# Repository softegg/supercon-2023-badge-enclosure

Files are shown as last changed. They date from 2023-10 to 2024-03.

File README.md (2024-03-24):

# supercon-2023-badge-enclosure
This is an enclosure for the Hackaday Supercon 2023 / Hackaday Berlin 2024 Vectorscope badge, which appears on GitHub here:
https://github.com/Hack-a-Day/Vectorscope/tree/main

These files are available for anybody to 3d print, modify, remix, etc. in advance of the 2023 Hackaday Superconference and Hackaday Berlin 2024 event, so that they might have an elegant enclosure for their badge.

I make them available under the Creative Commons Attribution-NonCommercial-ShareAlike 4.0 International License, which basically means you can do anything you want with this except make money on it. Only I can do that. Having posted it to GitHub implies that they might be getting some advantage out of it, and sharing pictures of it is fine, but please reproduce the license with any of the models you wish to redistribute.

https://creativecommons.org/licenses/by-nc-sa/4.0/deed.en

The intention is that there will be multiple versions of this enclosure.

Basic-2 is the most basic version (The original BASIC is depreciated; it was an early revision that didn't fit together well and you shouldn't use it anymore.) It is designed as a jumping off point for more elaborate designs with a simple, clean, rounded shape that shouldn't hurt you if you are wearing it.

BASIC-2-HACKING is a double sized version that is designed to fit the badge hacking expansion board as well. There is plenty of blank space for you to add your own controls, connectors, displays, stickers, whatever, and you are encouraged with both designs to remix them for whatever your hacking/aesthetic needs are!

If you print one and come to the show, I'd really like to get a selfie with you and your version of the badge, or if you are sensitive about your picture, I could just take a selfie with your badge. It was great fun at Supercon, and I hope to see a lot of these at Berlin 2024 as well!

The BASIC-2 Enclosure
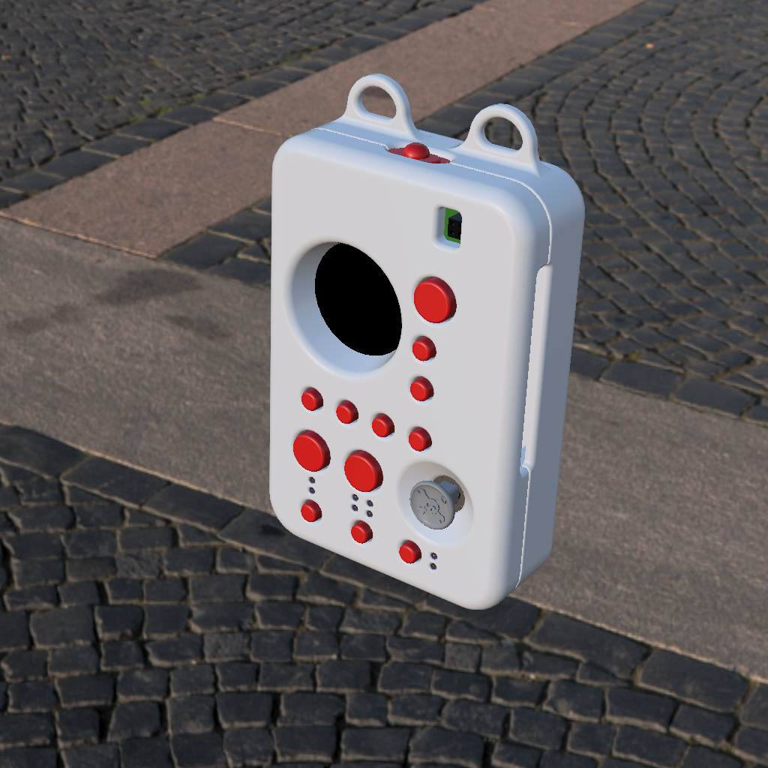
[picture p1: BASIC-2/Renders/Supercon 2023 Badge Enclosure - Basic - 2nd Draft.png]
The BASIC-2 Enclosure as rendered from Fusion 360


The BASIC-2-HACKING Enclosure
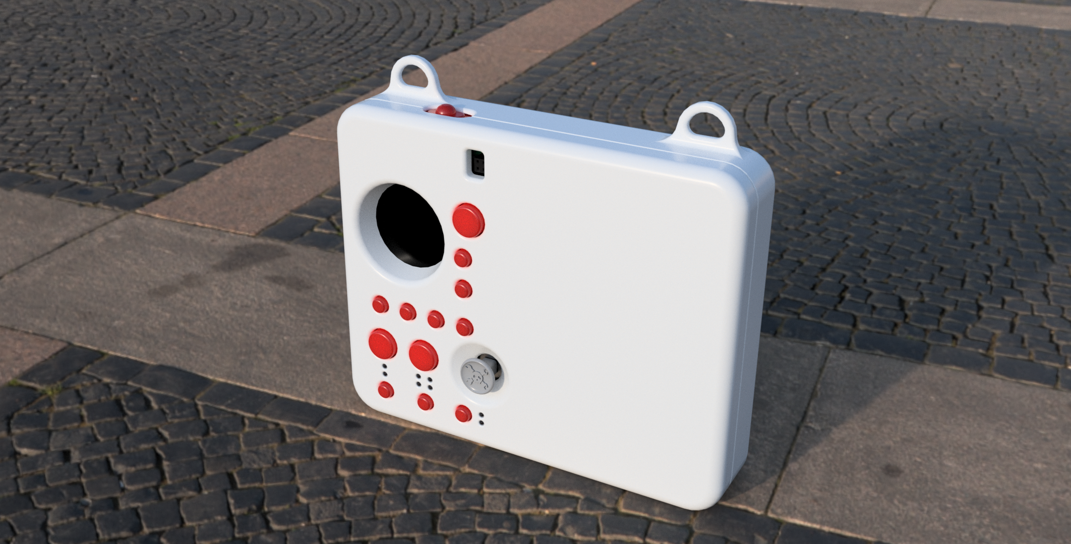
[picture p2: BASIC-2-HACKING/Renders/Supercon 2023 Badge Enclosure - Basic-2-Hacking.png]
The BASIC-2-HACKING Enclosure as rendered from Fusion 360


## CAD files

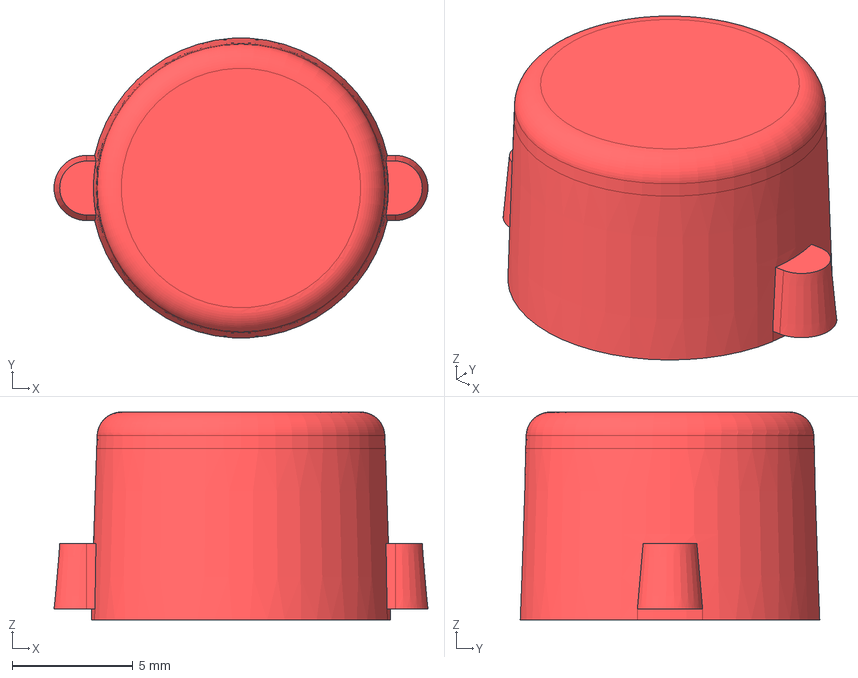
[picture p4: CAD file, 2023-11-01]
BASIC-2-HACKING/STEP/Menu Button - Supercon 2023 Badge Enclosure - Basic-2-Hacking.step
15.5 x 12.4 x 8.60 mm

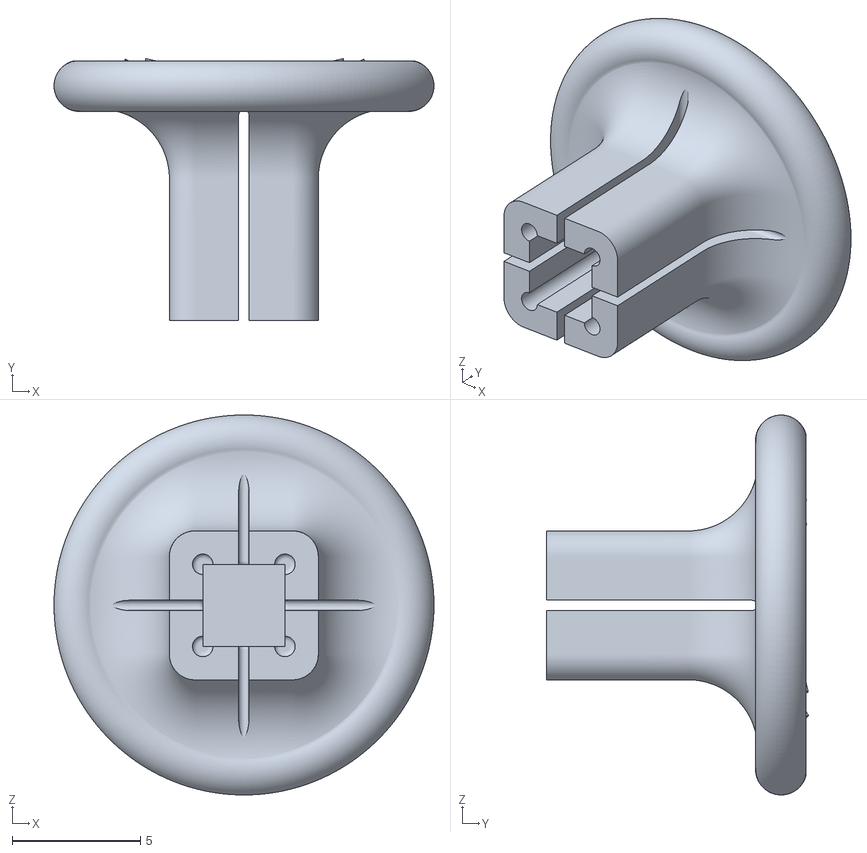
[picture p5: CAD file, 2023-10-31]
BASIC-2-HACKING/STL/Joystick - Supercon 2023 Badge Enclosure - Basic-2-Hacking.stl
14.8 x 10.2 x 14.8

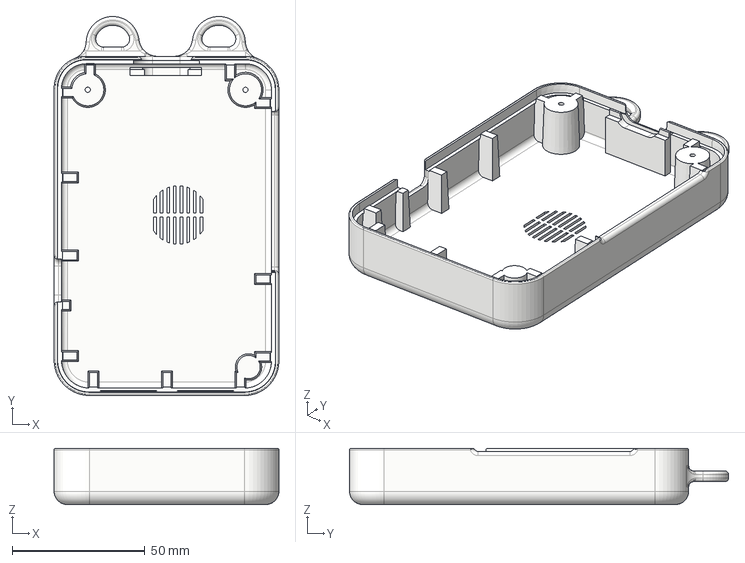
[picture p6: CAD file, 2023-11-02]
BASIC-2/STEP/Back - Supercon 2023 Badge Enclosure - Basic-2.step
84.6 x 142.6 x 21.1 mm

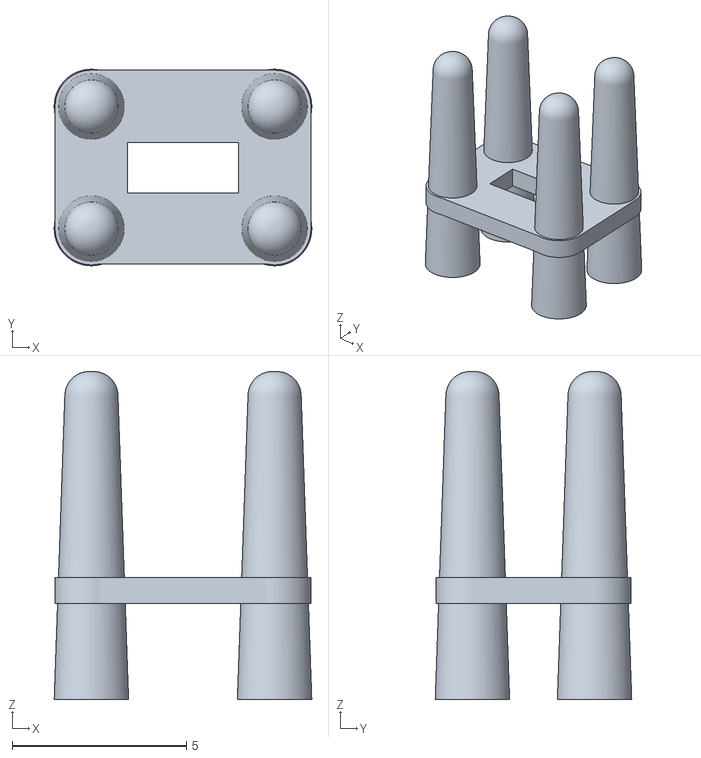
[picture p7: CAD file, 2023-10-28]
BASIC-2/STL/Lightpipe 2z2 - Supercon 2023 Badge Enclosure - BASIC-2.stl
7.38 x 5.63 x 9.40

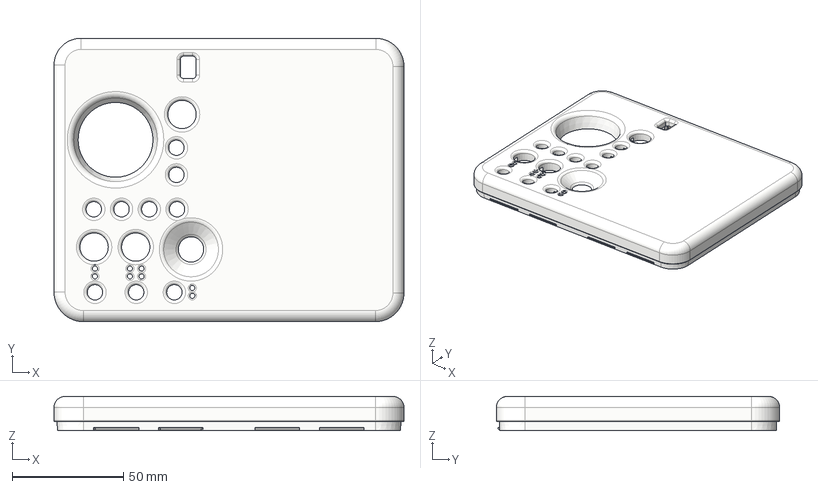
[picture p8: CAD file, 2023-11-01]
BASIC-2-HACKING/STEP/Front - Supercon 2023 Badge Enclosure - Basic-2-Hacking.step
157.6 x 127.6 x 15.4 mm

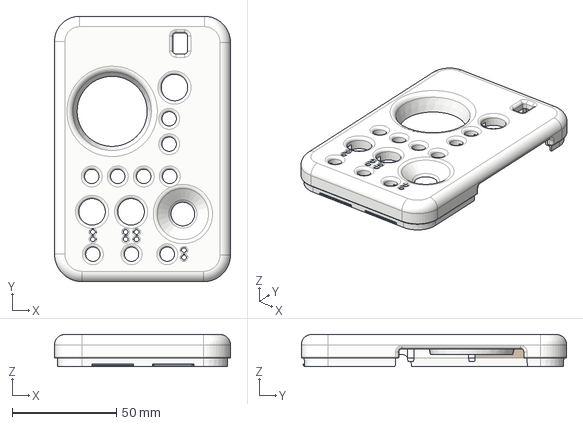
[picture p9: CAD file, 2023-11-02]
BASIC-2/STEP/Front - Supercon 2023 Badge Enclosure - Basic-2.step
84.6 x 127.6 x 15.4 mm

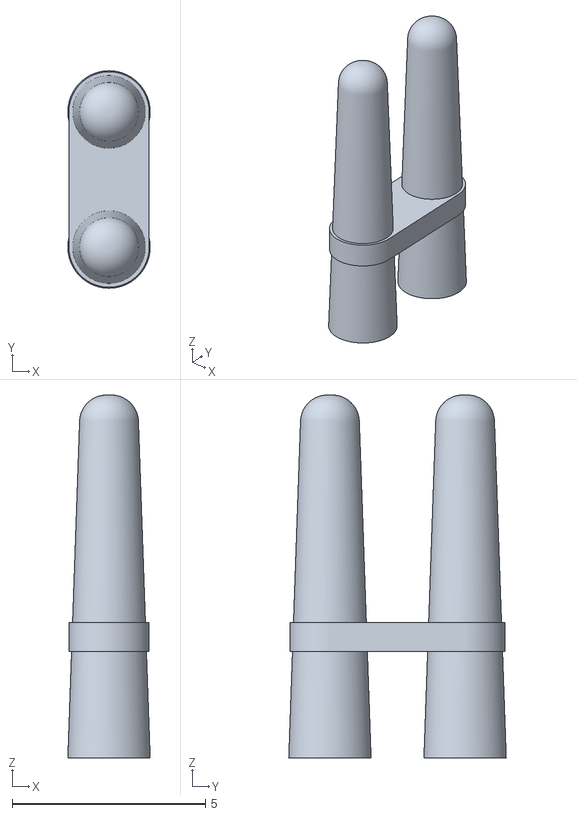
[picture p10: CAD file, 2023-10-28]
BASIC-2/STL/Lightpipe 1x2 - Supercon 2023 Badge Enclosure - BASIC-2.stl
2.13 x 5.63 x 9.40

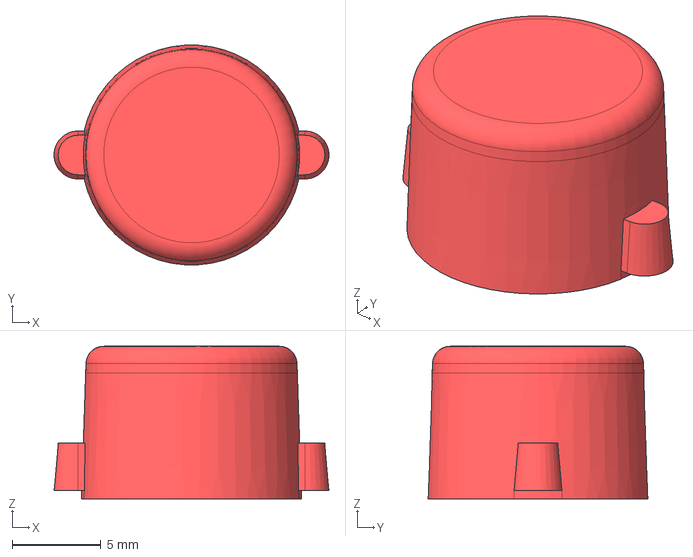
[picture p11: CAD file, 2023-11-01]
BASIC-2-HACKING/STEP/Level Button - Supercon 2023 Badge Enclosure - Basic-2-Hacking.step
15.5 x 12.4 x 8.60 mm

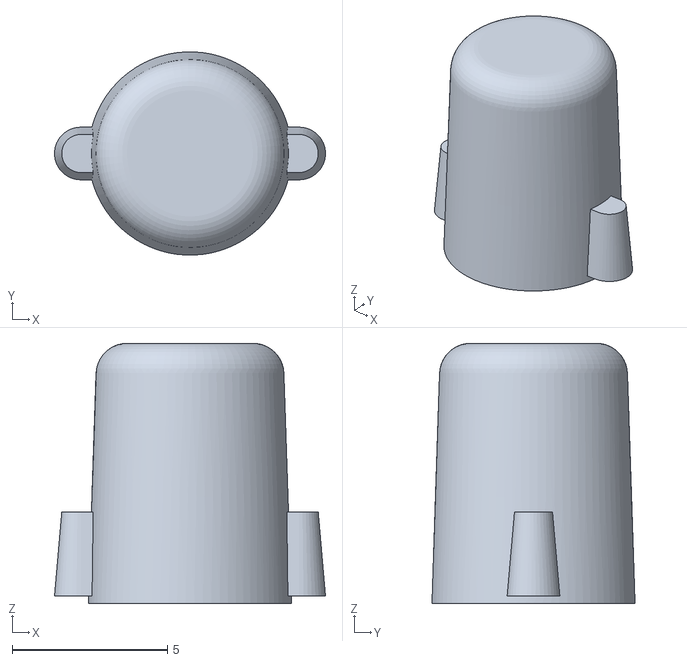
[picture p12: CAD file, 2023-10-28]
BASIC-2/STL/Button C.stl - Supercon 2023 Badge Enclosure - BASIC-2.stl
8.74 x 6.55 x 8.40

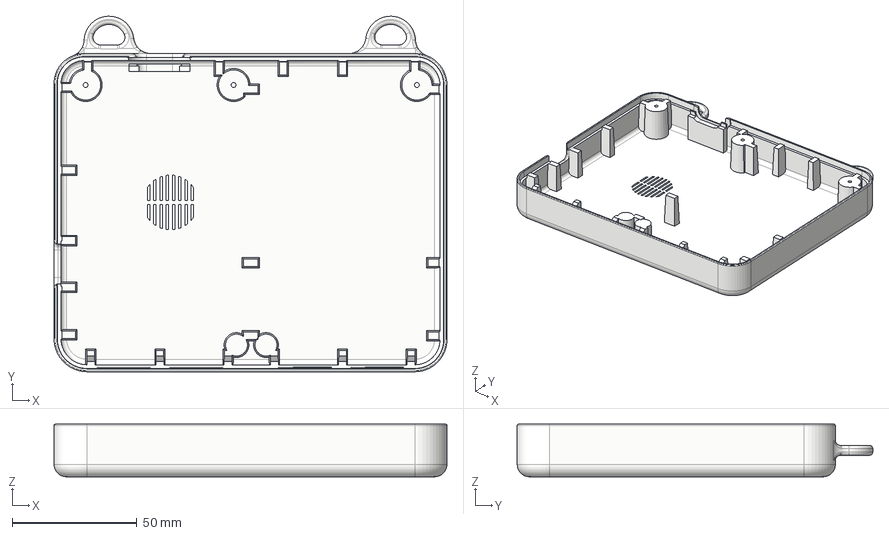
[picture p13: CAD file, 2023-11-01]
BASIC-2-HACKING/STEP/Back - Supercon 2023 Badge Enclosure - Basic-2-Hacking.step
157.6 x 142.6 x 21.1 mm

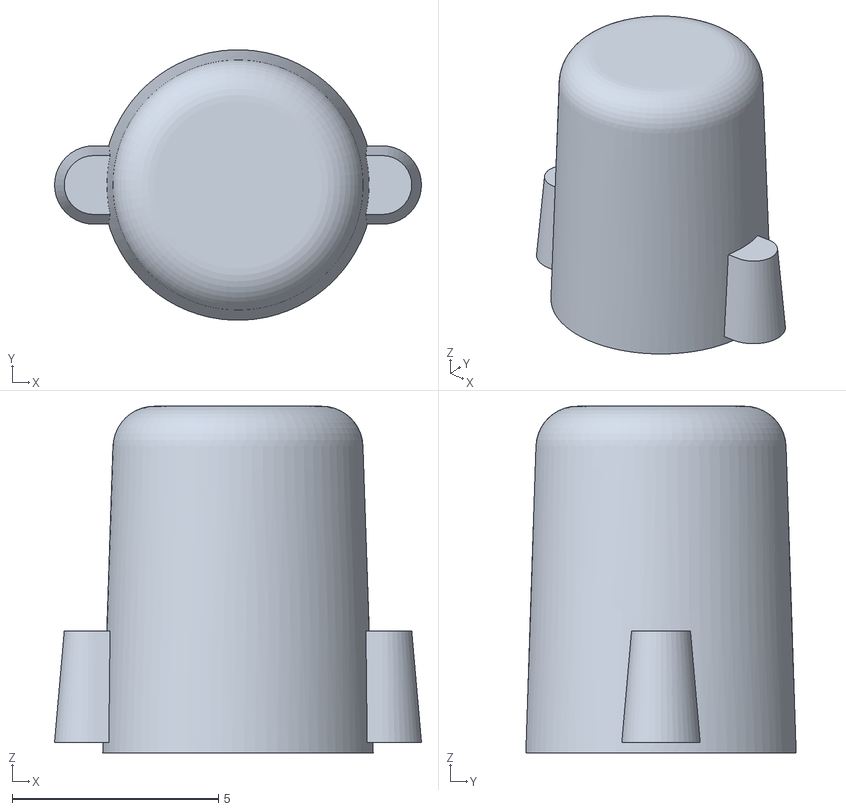
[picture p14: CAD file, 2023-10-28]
BASIC-2/STL/XY - Supercon 2023 Badge Enclosure - BASIC-2.stl
8.90 x 6.55 x 8.40

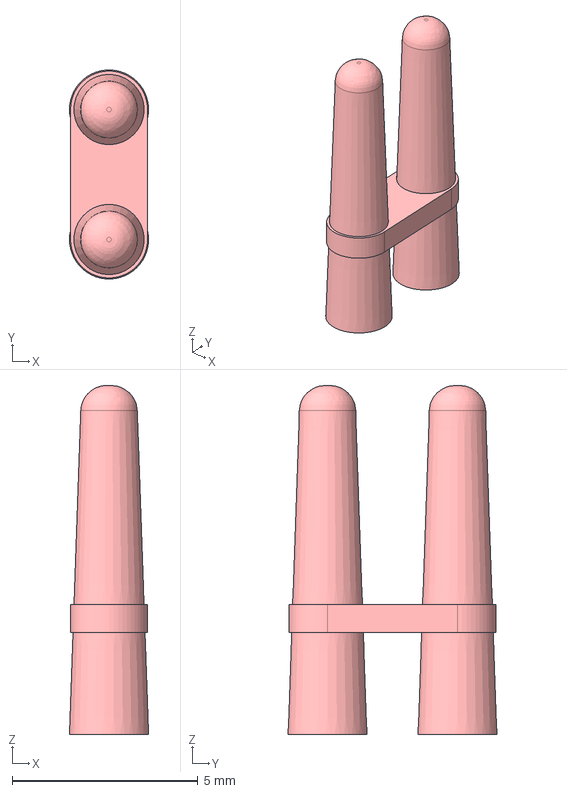
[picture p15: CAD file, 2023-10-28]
BASIC-2/STEP/Lightpipe 1x2 B - Supercon 2023 Badge Enclosure - Basic-2.step
2.13 x 5.63 x 9.40 mm

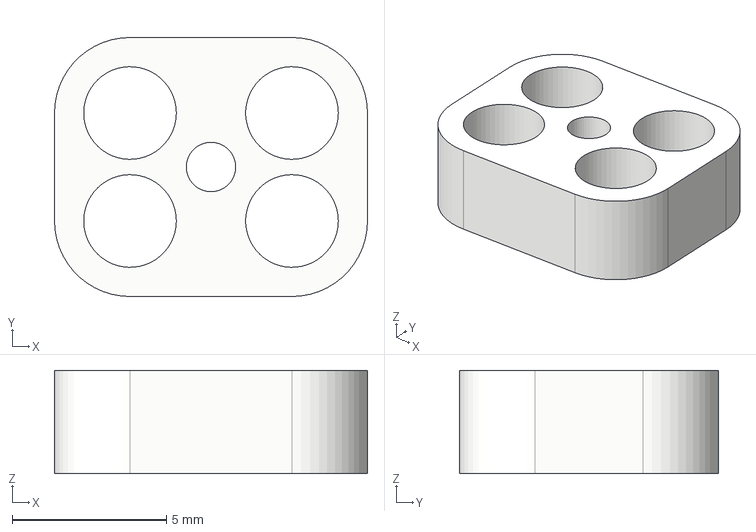
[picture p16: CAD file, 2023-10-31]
BASIC-2-HACKING/STEP/Lightpipe 2x2 Shield - Supercon 2023 Badge Enclosure - Basic-2-Hacking.step
10.1 x 8.39 x 3.35 mm

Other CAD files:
BASIC-2/STEP/Joystick - Supercon 2023 Badge Enclosure - Basic-2.step
BASIC-2/STEP/Lightpipe 2x2 - Supercon 2023 Badge Enclosure - Basic-2.step
BASIC-2-HACKING/STEP/Range Button - Supercon 2023 Badge Enclosure - Basic-2-Hacking.step
BASIC-2/STL/Button B.stl - Supercon 2023 Badge Enclosure - BASIC-2.stl
BASIC-2/STEP/Lightpipe 1x2A - Supercon 2023 Badge Enclosure - Basic-2.step
BASIC-2-HACKING/STEP/Button A - Supercon 2023 Badge Enclosure - Basic-2-Hacking.step
BASIC-2-HACKING/STEP/Button B - Supercon 2023 Badge Enclosure - Basic-2-Hacking.step
BASIC-2-HACKING/STEP/Button C - Supercon 2023 Badge Enclosure - Basic-2-Hacking.step
BASIC-2-HACKING/STEP/Button D - Supercon 2023 Badge Enclosure - Basic-2-Hacking.step
BASIC-2-HACKING/STEP/Lightpipe 1x2 A - Supercon 2023 Badge Enclosure - Basic-2-Hacking.step
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

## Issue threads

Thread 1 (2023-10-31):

Enclosure as a teachable experience

frankcohen, 2023-10-31:
Hi @softegg thanks for the case, I'm going to print it on a Elegoo Saturn resin printer in a clear resin. I'm working on my Reflections open-source wrist watch project https://github.com/frankcohen/ReflectionsOS. I've been wondering how I can make press-able buttons on the watch case that would activate SMT buttons on its main board. I'm hoping your badge enclosure will teach me about buttons.

One thing that concerns me about your enclosure... so many objects to print! Wow.

Thank you.

-Frank

softegg, 2023-10-31:
The best teacher is always to take apart some things that work the way you want your project to work and see what they did.

For buttons, the main things are that they don't bind and they don't fall in the case. If you have labels on them, maybe make sure they don't spin also.
Having a draft angle that makes them smaller near the top helps keep them in the case, but it is good to have some sort of a lip also. I used the spin prevention nubs for that, but that kinda means you can see LEDs blinking in the case around the buttons, so maybe I coulda done better with a full lip.
The design very much depends on what they are actually pushing, whether they can attach to that, if they need to come off for cleaning, how deep you enclosure is, etc.

You prototype until you have something that works, and try to produce it with a process that gets you as close to your finished process as possible.

In injection molding, you need draft angle to you can get the parts out of the mold, and vents so that the air has a way to escape when they plastic comes in. If it's deep, you might need a pusher to push the part out of the mold. And you need an easy parting line where the mold separate and the draft angle reverses. Oh, and an injection point for the plastic to go in.
Any hole or edge leaves a scar or sprue, so you want this in areas that you can't see, and that won't cause a mechanical failure to the motion of the button.
Resin casting is similar, but more forgiving because the silicon molds bend, but then you have to worry about part warping too, on larger parts. Also, mold release is really important so as not to tear the mold.

If you are 3d printing, you have different concerns. Resin is mainly about where your supports go, how resin drains, and build plate adhesion.
FDM has support, infill, grain, bed adhesion, resolution and a while host of other issues.

So you design your posts with your manufacturing process, both prototyping and manufacturing, in mind, as well as the mechanical function, and aesthetics.

It's fun, but there are always revisions and tweaks before you get it right. I'm amazed that the first draft enclosure came out as good as it did, TBH. But even that had buttons that bind...

Anyway, good luck. I'm available for hire if you don't want to do it yourself...

frankcohen, 2023-11-01:
Thanks for the advice, I appreciate you writing your advice to me.

I'm a software guy who is learning by doing a combination hardware/software project. Reflections first instance is a wrist watch. There are two surface mounted switches on the main board. They have push button pins on their sides. I need 2 easy buttons to be at the watch case and reach in to press the buttons on the main board.

My plan is to prototype the watch case using clear resin (printed on an Elegoo Saturn printer), then take the final prototypes to a manufacturer. The manufacturer builds the case design to be milled from stainless steel. I would be fine if you tell me not to do this process?

Not so great progress on printing the Supercon board protector today. Trying again tomorrow.

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

-Frank

Closed 2024-03-24.

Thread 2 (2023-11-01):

Printing All At Once

frankcohen, 2023-11-01:
My first print experiences for the enclosure didn't go so well. :-D
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

I rotated the case to keep it from adhering to the build plate. Instead, that's just what it did. :-o

My attempt today is to print all the components all at once. It's my homage to Jobu Tupaki, "I got bored one day and put everything on a bagel." Although perhaps this strategy will be more like Evelyn saying 'We are all small and stupid."

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

6 1/2 hours, 1,792 layers, and a full tank of water-washable clear resin... what could go wrong?

Please wish me luck!

See you all tomorrow!

-Frank

softegg, 2023-11-01:
Resin printing can be tricky. The first ones you did seem like they were perhaps not exposed long enough, and then not UV cured after the bath in IPA alcohol, maybe? I'm not an expert, either.
Have you done resin prints before? Have these settings worked on other projects?
What I do know is that you have to be very careful to try not to print large areas unless they are attached to a large amount of support from previous layers or from added supports. Otherwise it glues itself to the FEP film and you don't end up with a print, you end up with a big flat blob.
But that doesn't seem to be your problem.

Obviously, the model doesn't really have anything to do with it, so I can only suggest that your machine is probably not set up correctly for the resin that you are using. Also, make sure to get the bubbles out of the resin before you start printing. You never shake up resin, you kinda slosh it for a few minutes, trying not to get air bubbles in it, before pouring it into the tray. I usually rake it a few times with the plastic spatula (being careful not to scrape the FEP film!)  to make sure it is mixed and to move remaining bubbles out of the build area.

Anyway, sorry if I am over-explaining stuff you already know!

Good luck with your prints!

frankcohen, 2023-11-02:
Not overexplaining, cause I'm not the only one printing tonight! :-D

I've been printing on this Elegoo Saturn S for about 6 months and it works great.

You did a fine job at building the model. The print set-up includes how to support the model, how to avoid FEP bunching, printing large areas, as you say. The model could have been broken down into smaller interlocking pieces to make printing easier.

It's printing over night tonight. You'll ether see me with a kickass crystal board protector, or not. Either way it's been a good learning experience! Thanks!

-Frank

frankcohen, 2023-11-02:
Better...
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

frankcohen, 2023-11-02:
One more try before I get onto the flight tomorrow

frankcohen, 2023-11-02:
Success! See you all tomorrow. -Frank

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

frankcohen, 2023-11-02:
sorry, here are the correct photos.
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

softegg, 2024-03-24:
Glad it all worked out!

Closed 2024-03-24.

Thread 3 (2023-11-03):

Feedback

nickwinn, 2023-11-03:
Overall the case is good, would recommend adding a method of easily changing the batteries (like a snap on back that isn't screwed on).

softegg, 2023-11-23:
Hey, the files are all here for you!
Feel free to fork the project and add the features you want!

softegg, 2024-03-24:
I'm gonna mark this as closed because I don't really intend to make any changes at this point. This badge design is a jumping off point for the user to make their own changes, and I encourage everybody to fork the project and do just that.
Please share your changes on GitHub when you do!

Closed 2024-03-24.

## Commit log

2023-10-24 Create license.txt
    This project licensed under the CC BY-NC-SA 4.0 license.
    The Creative Commons Attribution-NonCommercial-ShareAlike 4.0 International License
    https://creativecommons.org/licenses/by-nc-sa/4.0/deed.en
    You are free to:
    Share — copy and redistribute the material in any medium or format
    Adapt — remix, transform, and build upon the material
    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
2023-10-24 First draft of Basic Style Enclosure.
    This is the untested first draft of the Basic Style Enclosure.
    [Back - Supercon 2023 Badge Enclosure - Basic v4.step, Button A - Supercon 2023 Badge Enclosure - Basic v4.step, Button B - Supercon 2023 Badge Enclosure - Basi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]
2023-10-24 Basic Enclosure - First Check In!
    Step and STL files for the Basic Enclosure
    Untested
    [Back - Supercon 2023 Badge Enclosure - Basic v4.step, Back Front - Supercon 2023 Badge Enclosure - Basic.stl, Button A - Supercon 2023 Badge Enclosure - Basic 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]
2023-10-24 Screw holes, front lip, and strap hangers added
    [Back - Supercon 2023 Badge Enclosure - Basic.stl, Front - Supercon 2023 Badge Enclosure - Basic.stl]
2023-10-24 Screwholes, front lip, and strap hangers added.
    [Back - Supercon 2023 Badge Enclosure - Basic v4.step, Front - Supercon 2023 Badge Enclosure - Basic v4.step]
2023-10-24 Updated with screw holes and strap hangers
2023-10-26 Pictures of the very first 3d print October 25th
    The buttons need more tolerance.
    The lip seemed to have trouble.
    Cleaning out the support material was awful
2023-10-27 Official Thumbstick - doesn't work w/enclosures
2023-10-28 2nd version of BASIC
    [Back - Supercon 2023 Badge Enclosure - BASIC-2.stl, Back - Supercon 2023 Badge Enclosure - Basic-2.step, Button A - Supercon 2023 Badge Enclosure - BASIC-2.stl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]
2023-10-28 Delete BASIC-2/Supercon 2023 Badge Enclosure - Basic - 2nd draft.f3z
    moved this file to the Fusion directory
2023-10-28 An example layout of all parts in Cura
    [CFFFP_Front - Supercon 2023 Badge Enclosure - Basic - Flip.3mf]
2023-10-28 Update lightpipes for better fit
    [Lightpipe 1x2 - Supercon 2023 Badge Enclosure - BASIC-2.stl, Lightpipe 1x2 B - Supercon 2023 Badge Enclosure - BASIC-2.stl, Lightpipe 2z2 - Supercon 2023 Badge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]
2023-10-28 Update lightpipes in STEP. Add a complete STEP
    [Lightpipe 1x2 B - Supercon 2023 Badge Enclosure - Basic-2.step, Lightpipe 1x2A - Supercon 2023 Badge Enclosure - Basic-2.step, Lightpipe 2x2 - Supercon 2023 Ba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]
2023-10-30 BASIC 2 badge HACKING version
    [Back - Supercon 2023 Badge Enclosure - Basic-2-Hacking.step, Back - Supercon 2023 Badge Enclosure - Basic-2-Hacking.stl, Button A - Supercon 2023 Badge Enclosu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]
2023-10-30 Renders of hacking version of badge enclosure
2023-10-31 Updated Thumbstick with strain relief that works.
    Updated Thumbstick with strain relief that works.
    This should probably print ok on a potato, but use a decent resolution if you can, ok?
    [Joystick - Supercon 2023 Badge Enclosure - BASIC-2.stl]
2023-10-31 Updated Thumbstick with Strain Relief
    Updated Thumbstick with Strain Relief.
    This should probably print ok on a potato, but try and use a decent resolution, ok?
    [Joystick - Supercon 2023 Badge Enclosure - Basic-2-Hacking.stl]
2023-10-31 Thumbstick update with Strain Relief.
    [Thumbstick - Supercon 2023 Badge Enclosure - Basic-2-Hacking.step]
2023-10-31 Thumbstick updated with strain relief
    [Joystick - Supercon 2023 Badge Enclosure - Basic-2.step]
2023-10-31 Lightpipe isolation, Power Switch slider stuff
    [Back - Supercon 2023 Badge Enclosure - Basic-2-Hacking.stl, Lightpipe 1x2 A - Supercon 2023 Badge Enclosure - Basic-2-Hacking.stl, Lightpipe 1x2 A Shield - Sup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]
2023-10-31 Lightpipe isolation, Power Switch slot stuff, Hook
    [Back - Supercon 2023 Badge Enclosure - Basic-2-Hacking.step, Front - Supercon 2023 Badge Enclosure - Basic-2-Hacking.step, Lightpipe 1x2 A - Supercon 2023 Badg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]
2023-11-01 Put screw holes back. Longer Big Buttons. Lightpipes longer.
    [Back - Supercon 2023 Badge Enclosure - Basic-2-Hacking.stl, Front - Supercon 2023 Badge Enclosure - Basic-2-Hacking.stl, Level Button - Supercon 2023 Badge Enc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]
2023-11-01 Screw holes are back. Lightpipes longer+shields, Longer big buttons
    [Back - Supercon 2023 Badge Enclosure - Basic-2-Hacking.step, Front - Supercon 2023 Badge Enclosure - Basic-2-Hacking.step, Level Button - Supercon 2023 Badge E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]
2023-11-01 Screw holes are back.
2023-11-02 Added switch slider on top as well. Switch slider slightly wider.
    [Back - Supercon 2023 Badge Enclosure - BASIC-2.stl]
2023-11-02 Added switch slider on front. Switch slider more spacing.
    [Back - Supercon 2023 Badge Enclosure - Basic-2.step, Front - Supercon 2023 Badge Enclosure - Basic-2.step]
2023-11-02 Top switch slider, PCB support fixes
2024-03-02 Delete BASIC directory
    BASIC-2 and BASIC-2 HACKING are the only ones that should be used.
    [Back - Supercon 2023 Badge Enclosure - Basic v4.step, Back - Supercon 2023 Badge Enclosure - Basic.stl, Back Front - Supercon 2023 Badge Enclosure - Basic.stl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]
2024-03-24 Update README.md
    Added a pic of the BASIC-2-HACKING enclosure
